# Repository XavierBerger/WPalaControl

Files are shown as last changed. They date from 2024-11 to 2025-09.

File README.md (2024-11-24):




# WPalaControl

**WPalaControl** is a device designed to control and monitor Fumis-based stoves using a D1 Mini.  
It allows you to power on/off, adjust the set point, change fan speeds, and retrieve status, alarms, and temperature data from your stove.  

It supports native HTTP requests which makes it fully compatible with all existing Palazzetti/Fumis home automation plugins/apps.  

It also integrates with MQTT to monitor/control your stove in a much more efficient way.  

## Stove Compatibility

WPalaControl is compatible with stoves using the Fumis Controller, which is used by many manufacturers, including:  
  
Palazzetti / Jotul / TurboFonte / Godin / Fonte Flamme / Invicta / Casatelli / Alpis / Faizen / HETA / ...

To determine if your stove is compatible with WPalaControl, look for the following Control Panel or Motherboard:  
Fumis ControllerFumis Controller

## Home Automation compatibility

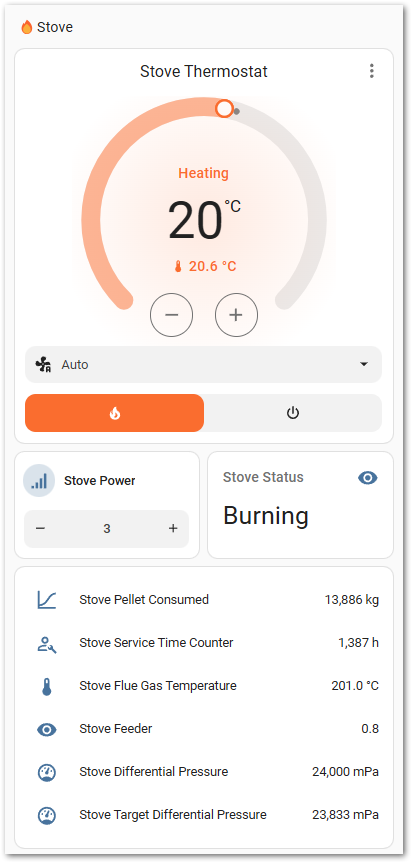
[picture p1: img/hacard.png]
hacard
| Logo HASS | [MQTT Integration](https://www.home-assistant.io/integrations/mqtt/) (autodiscovery) <br> Most options and fans control |  |
| --- | --- | --- |
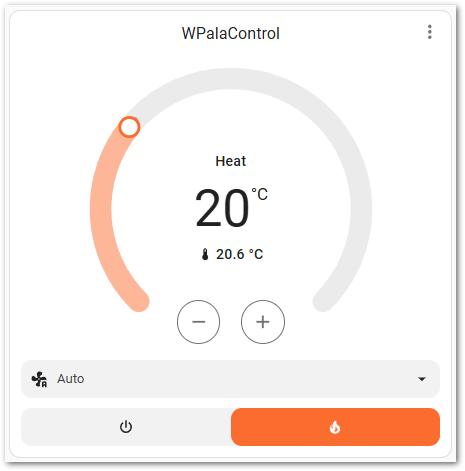
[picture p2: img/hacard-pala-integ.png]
hacard-pala-integ
| Logo HASS | [Palazzetti Integration](https://www.home-assistant.io/integrations/palazzetti)<br> (2024.11 minimum) <br> Basic implementation for now |  |
| Logo Jeedom | [Palazzetti plugin](https://www.jeedom.com/market/index.php?v=d&p=market_display&id=3104) | Jeedom widget |

## Make/Get your adapter

complete Module

🔧 If you want to build it yourself, you can find all details here : [BUILD](BUILD.md) 🔧  

🛍️🚀 Otherwise, I'm producing some small batches and offering it ready-to-use here :  
Tindie product (https://www.tindie.com/products/35770/)  

## Connect

⚠️ **Before connecting, please check that you are using the correct cable**  
For Hardware V1.x: please use a **Crossed** cable  
For Hardware V2.x: please use a **Straight** cable  
_(Hardware version is written on the box and on the PCB)_

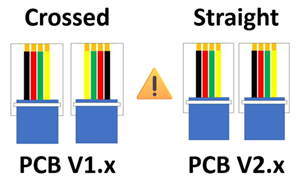
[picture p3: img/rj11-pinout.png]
WPalaControl rj11


✅If your stove has an accessible RJ12 connector, simply connect the cable.  

🔍If not, you'll need an additional cable and a splitter.  
➡️ More details can be found in the [Splitter Cabling documentation](SPLITTERCABLING.md)

## First Boot

During the first Boot, the WPalaControl creates its own Wi-Fi network (AP mode)  

Firmware version **3.2.0 and higher**:  

- Network SSID : `WPalaControl`
- Password : `password`

Version **3.1.x and lower**:  

- Network SSID : `WirelessPalaControlXXXX`
- Password : `PasswordPalaControl`

You should be automatically redirected to the module page.  
If not, go to 👉 <http://wpalacontrol.local> 👈

## Configuration pages

### Status

Provides useful informations about the module and the stove.  
**The stove SN appears then followed, 1 minute later, by refreshed stove information**  
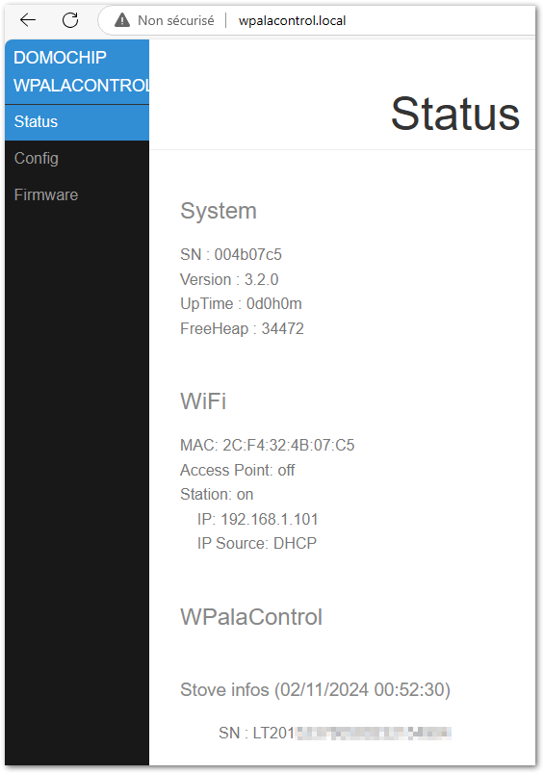
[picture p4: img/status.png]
status screenshot
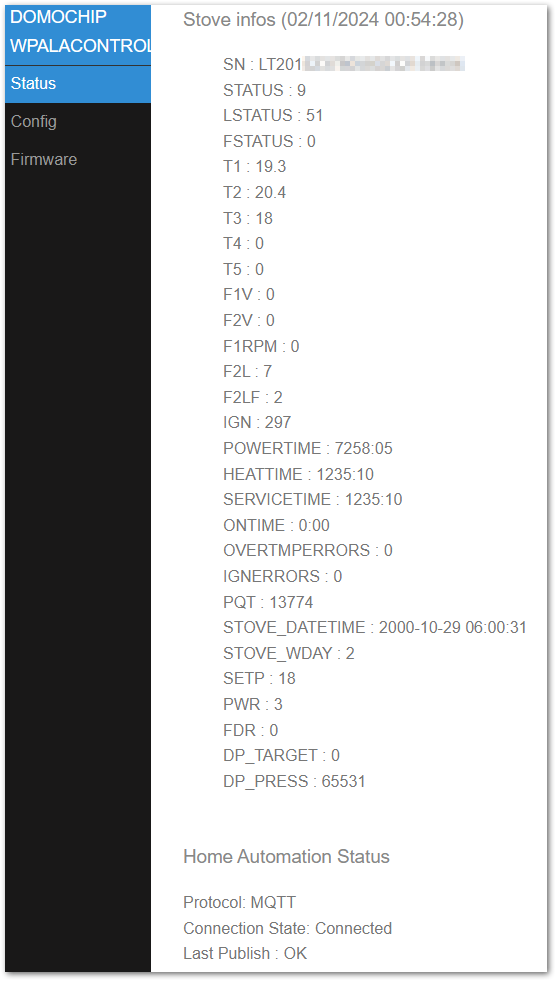
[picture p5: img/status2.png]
status2 screenshot


### Config

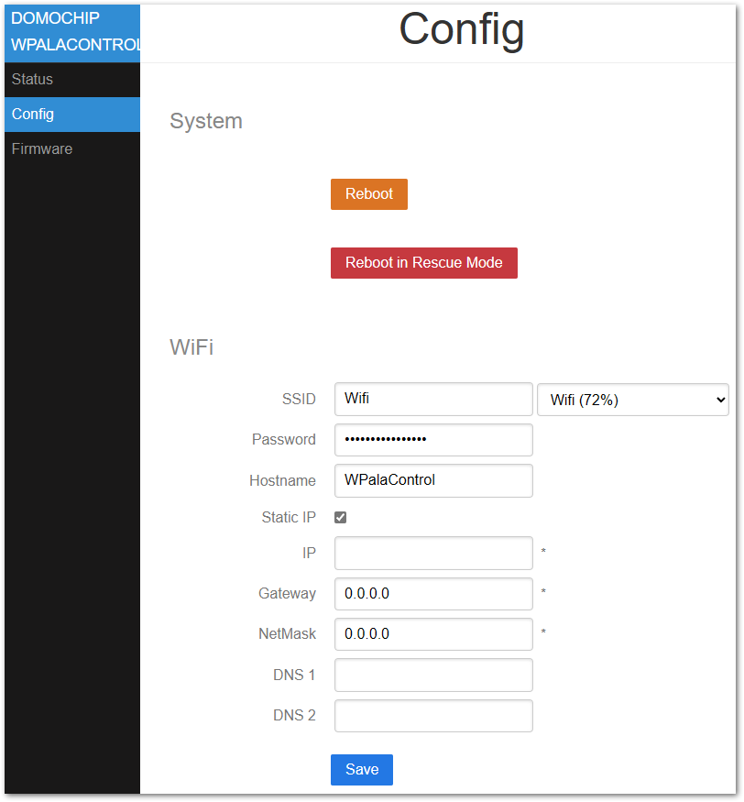
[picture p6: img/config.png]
config screenshot


#### System

- **Reboot**: restart the module
- **Reboot in Rescue Mode**: restart the module with default configuration

#### WiFi

- **ssid & password**: IDs of your Wifi Network  
- **hostname**: name of ESP on the network  
- **IP, GW, NetMask, DNS1&2**: Fixed IP configuration  

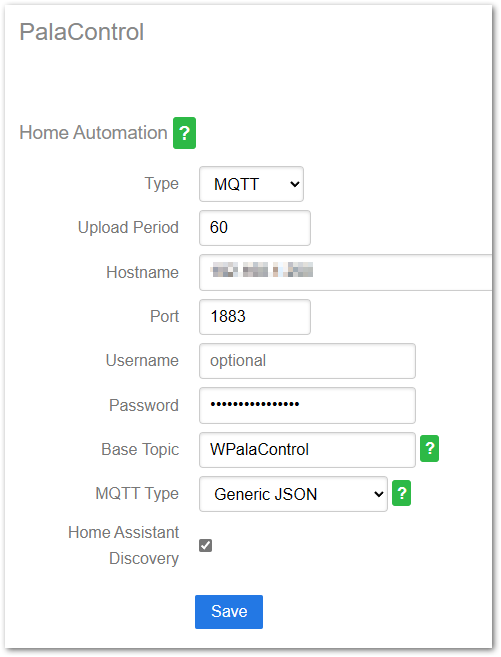
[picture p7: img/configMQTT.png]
configMQTT screenshot


#### PalaControl - Home Automation

- **Type**: enable/disable MQTT communication  
- **Upload Period**: set the refresh interval of stove information (in seconds)  
- **Hostname, Port, Username, Password**: MQTT server details (username and password are - optional)  
- **Base Topic**: prefix for WPalaControl topic structure  
- **MQTT Type**: defines MQTT topics and data structure:  
  - **Generic**: publish raw values under the base topic (e.g. "{baseTopic}/T1" = "*20.00*")
  - **Generic JSON**: publish values JSON to "category" topic under base topic (e.g. "{baseTopic}/TMPS" = "*{"INFO":{"CMD":"GET TMPS","RSP":"OK......*")
  - **Generic Categorized**: publish raw values to "category" topic under base topic (e.g. "{baseTopic}/TMPS/T1" = "*20.00*")
- **Home Assistant Discovery**: Enable/disable Home Assistant auto-discovery

### Firmware

Aallows you to flash a new firmware version directly from GitHub releases or using `WPalaControl.*.bin` or `WirelessPalaControl.*.bin` file:  
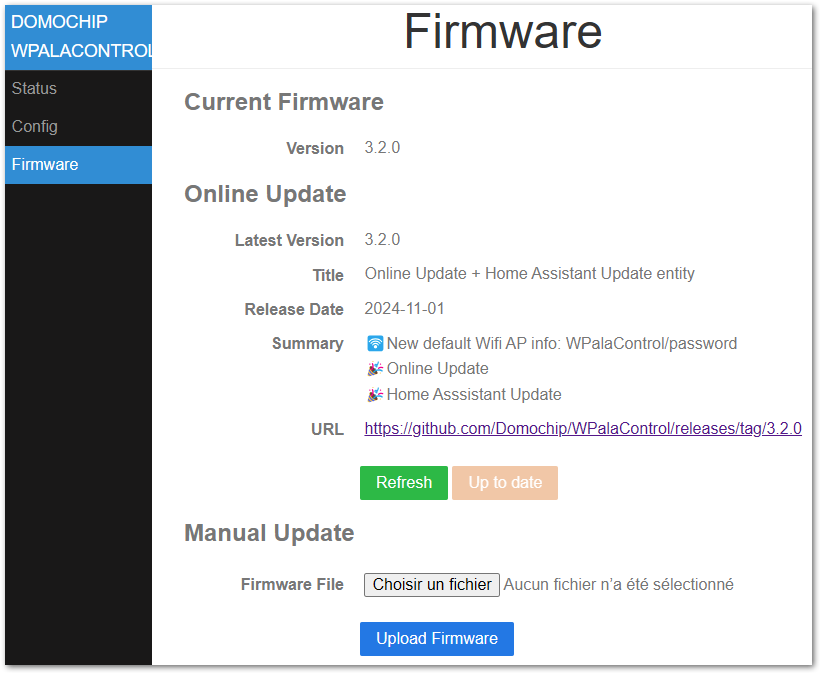
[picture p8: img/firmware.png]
firmware screenshot
  
Ensure the module has Internet access and/or DNS configured if IP address is static

## Use it

### HTTP

Natively, HTTP GET request can be sent directly to the module.  

```
http://wpalacontrol.local/cgi-bin/sendmsg.lua?cmd={command}
```

### MQTT

Send commands via MQTT to `%BaseTopic%/cmd` topic once MQTT is configured.  
Execution result is:

- published following the configured MQTT Type
- published on `%BaseTopic%/result` in JSON format

Module connection status is published to `%BaseTopic%/connected`:

- 0: not connected
- 1: connected but no communication with the stove
- 2: module and stove connected

### Command List
  
- `GET+STDT`: get static data
- `GET+ALLS`: get all status data
- `GET+STAT`: get status of the stove⏲️
- `GET+TMPS`: get temperatures of the stove⏲️
- `GET+FAND`: get Fan values⏲️
- `GET+SETP`: get current Set Point (desired temperature)⏲️
- `GET+POWR`: get current power (1-5)⏲️
- `GET+CUNT`: get some counters
- `GET+CNTR`: get some counters (same as GET+CUNT)⏲️
- `GET+DPRS`: get delta pressure data⏲️
- `GET+TIME`: get stove clock data⏲️
- `GET+IOPT`: get IO ports status
- `GET+SERN`: get stove Serial Number
- `GET+MDVE`: get stove model and fw version
- `GET+CHRD`: get chrono data
- `GET+PARM+92`: get parameter (ex : 92=pellet type (1-3))
- `GET+HPAR+57`: get hidden parameter (ex : 57=% of pellet to feed for pellet type 3)
- `BKP+PARM+CSV`: get all parameters in a CSV file (HTTP only) ✨
- `BKP+PARM+JSON`: get all parameters in a JSON file (HTTP only) ✨
- `BKP+HPAR+CSV`: get all hidden parameters in a CSV file (HTTP only) ✨
- `BKP+HPAR+JSON`: get all hidden parameters in a JSON file (HTTP only) ✨
- `CMD+ON`: turn stove ON
- `CMD+OFF`: turn stove OFF
- `SET+POWR+3`: set power (1-5)
- `SET+PWRU`: increase power by 1 unit
- `SET+PWRD`: decrease power by 1 unit
- `SET+SETP+20`: set Set Point (desired temperature)
- `SET+STPF+19.8`: set Set Point with a 0.2° precision (depend of your stove model)✨
- `SET+STPU`: increase Set Point by 1 unit
- `SET+STPD`: decrease Set Point by 1 unit
- `SET+RFAN+7`: set Room Fan value (0-5;6=Max;7=Auto)
- `SET+FN2U`: increase Room Fan by 1 unit
- `SET+FN2D`: decrease Room Fan by 1 unit
- `SET+FN3L+0`: set Room Fan 3 value (0-5)
- `SET+FN4L+0`: set Room Fan 4 value (0-5)
- `SET+SLNT+0`: set Silent mode value (0-1)
- `SET+TIME+2023-12-28+19:42:00`: set stove Date and Time (2000-2099) (1-12) (1-31) (0-23) (0-59) (0-59)
- `SET+CSST+0`: set Chrono Status value (0-1)
- `SET+CSTH+2+18`: set Chrono Program Start Hour (1-6) (0-23)
- `SET+CSTM+2+30`: set Chrono Program Start Minute (1-6) (0-59)
- `SET+CSPH+2+22`: set Chrono Program Stop Hour (1-6) (0-23)
- `SET+CSPM+2+45`: set Chrono Program Stop Minute (1-6) (0-59)
- `SET+CSET+2+19`: set Chrono Program Set Point (1-6) (desired temperature)
- `SET+CDAY+7+3+6`: set Chrono Program for week day (Day-Mem-Prog) (1-7) (1-3) (1-6)
- `SET+CPRD+1+19+18+30+22+45`: set Chrono Program data (Prog-Temp-StartH-StartM-StopH-StopM) (1-6) (temperature) (0-23) (0-59) (0-23) (0-59)
- `SET+PARM+92+2`: set parameter 92 to value 2 (ex : 92=pellet type (1-3))
- `SET+HPAR+57+95`: set hidden parameter 57 to value 95 (ex : 57=% of pellet to feed for pellet type 3)

⏲️: Published automatically  
✨: WPalaControl specific commands

### Description

MQTT infos published every "Upload Period":

- `STATUS`: status of the stove
- `LSTATUS`: status of the stove
- `T1`, `T2`, `T3`, `T4`, `T5`: temperature of the stove
- `F1V`, `F2V`, `F2L`, `F2LF`, `F3L`, `F4L`: fan values (meaning depend of your stove model)
- `IGN`: ignition counter
- `IGNERRORS`: ignition error counter
- `POWERTIME`: total heating time (hour:minute)
- `HEATTIME`: ??? (hour:minute)
- `SERVICETIME`: heating time since last maintenance (hour:minute)
- `ONTIME`: time from last power ON (hour:minute)
- `OVERTMPERRORS`: overtemperature error counter
- `STOVE_DATETIME`: date of the stove
- `STOVE_WDAY`: week day of the stove
- `SETP`: current Set Point (desired temperature)
- `PQT`: wood pellet consumption
- `PWR`: current power (1-5)
- `FDR`: feeder
- `DP_TARGET`: delta pressure target
- `DP_PRESS`: actual delta pressure

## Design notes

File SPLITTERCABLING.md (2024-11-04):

## Splitter Cabling

If your stove has no visible RJ12 connector, you'll neded to add a cable and a splitter between the controller and the control panel like this:  

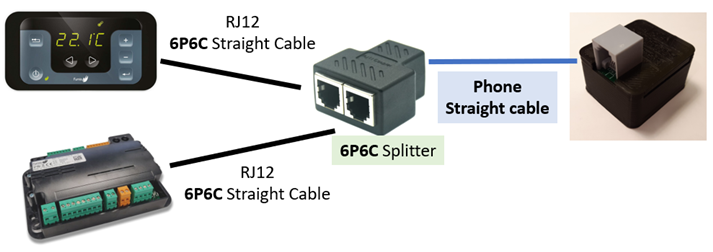
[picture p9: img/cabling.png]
WPalaControl cabling


The splitter should correspond to this small schematic :  
WPalaControl schematic-splitter

I'm offering these as an option on my store if needed

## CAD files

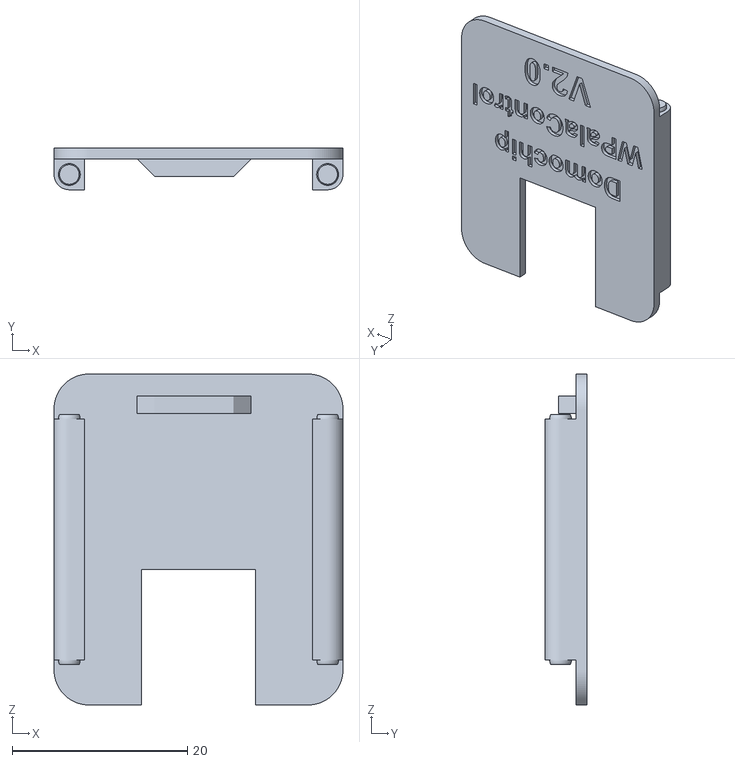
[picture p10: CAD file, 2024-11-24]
box/WPalaControl Lid.stl
33.0 x 4.75 x 37.8

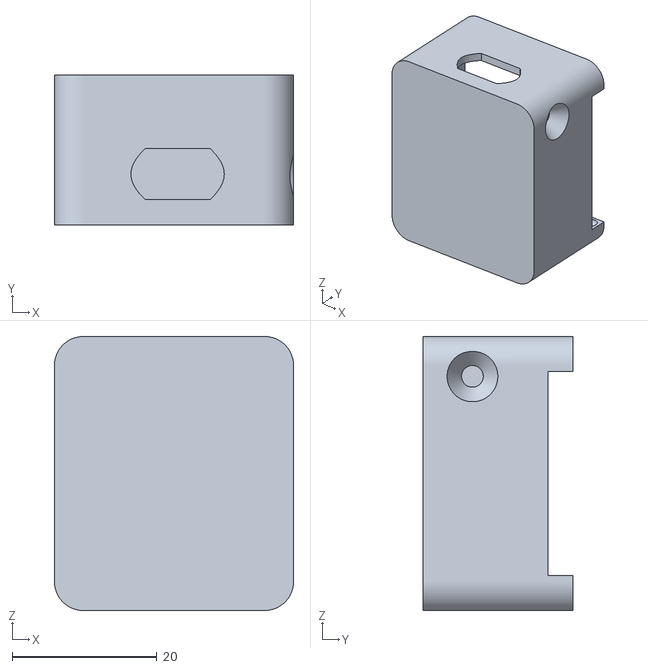
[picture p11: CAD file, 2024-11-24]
box/WPalaControl Box.stl
33.0 x 20.8 x 37.8

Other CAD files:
box/WPalaControl v17.f3d

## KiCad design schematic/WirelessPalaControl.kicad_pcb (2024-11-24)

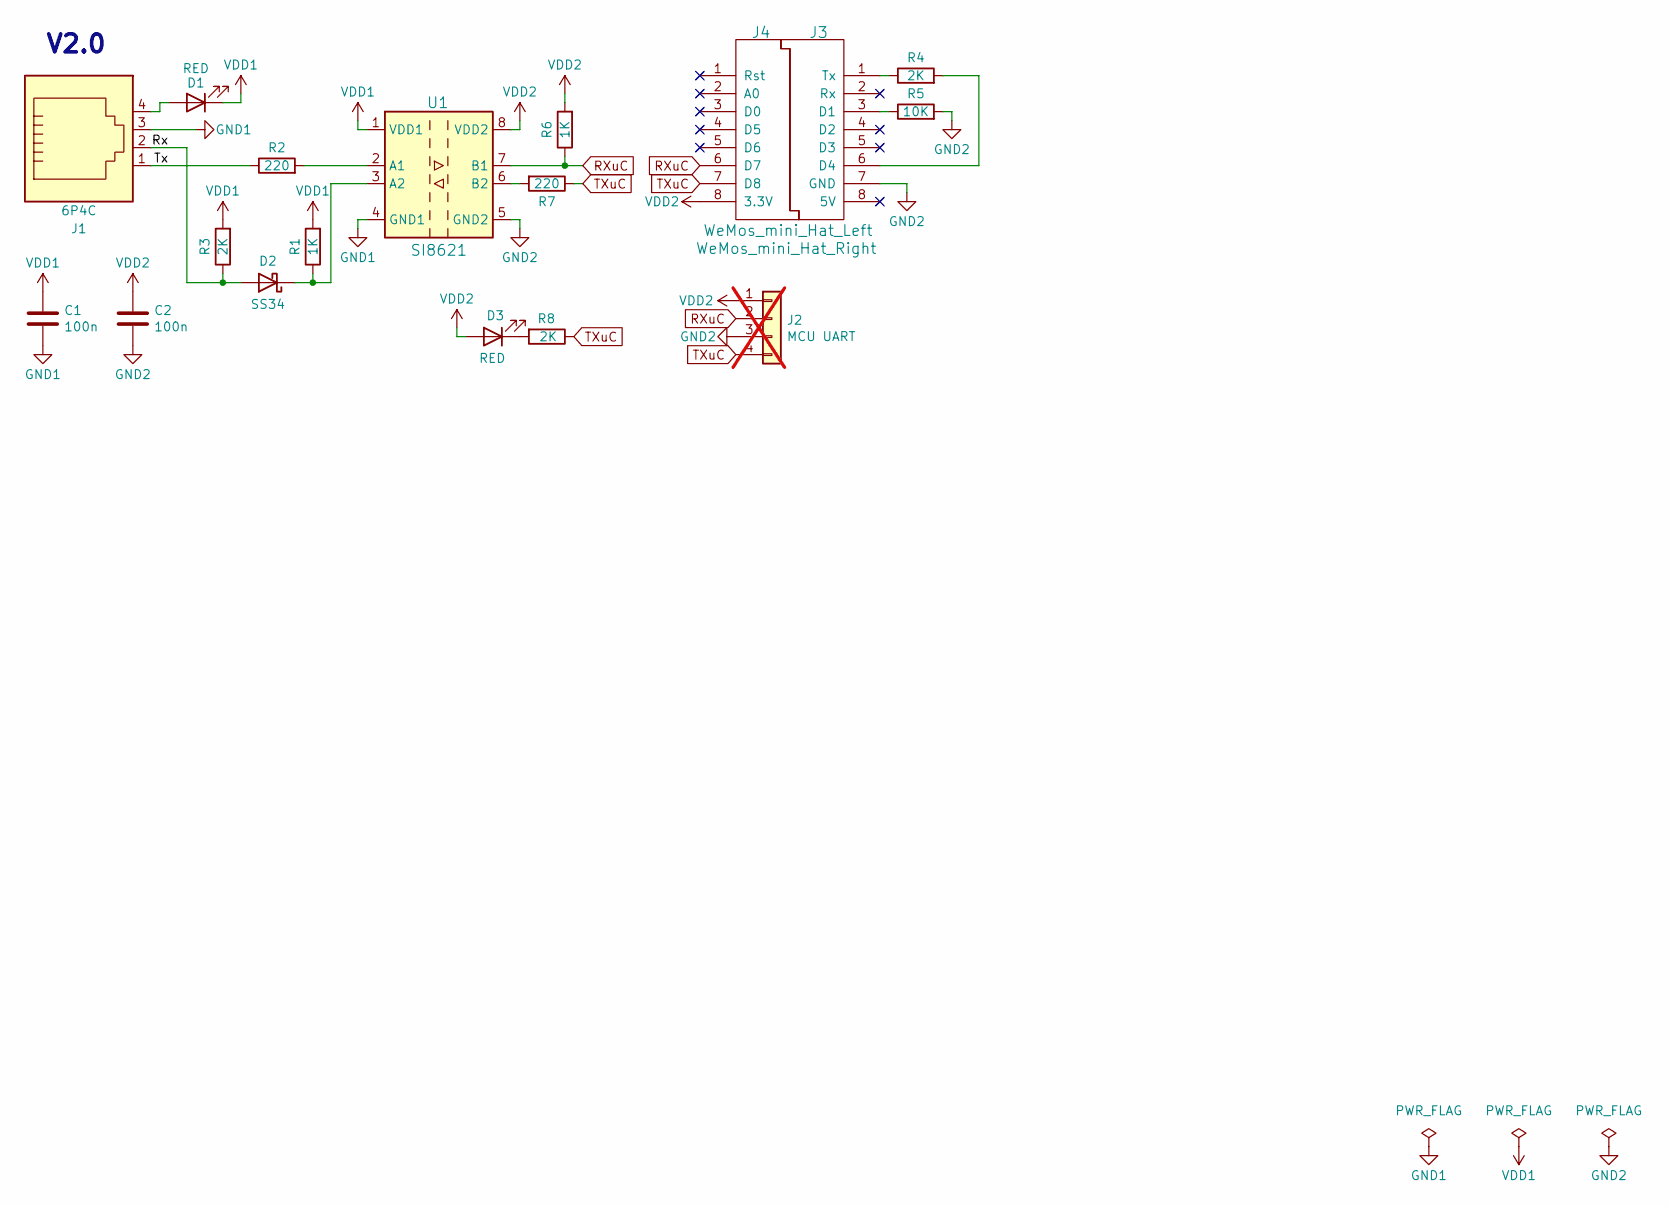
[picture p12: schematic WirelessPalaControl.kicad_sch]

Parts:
C1, C2: 100n; C_0805_2012Metric_Pad1.18x1.45mm_HandSolder; LCSC C49678
D1, D3: RED; LED_0805_2012Metric_Pad1.15x1.40mm_HandSolder; LCSC C84256
D2: SS34; D_SMA; LCSC C8678
J1: 6P4C; Ali_RJ11; LCSC C189749
J2: MCU UART; PinHeader_1x04_P2.54mm_Vertical; not fitted
J3: WeMos_mini_Hat_Left; WeMos_D1_mini_Hat_Left; LCSC C7509515
J4: WeMos_mini_Hat_Right; WeMos_D1_mini_Hat_Right; LCSC C7509515
R1, R6: 1K; R_0805_2012Metric_Pad1.20x1.40mm_HandSolder; LCSC C17513
R2, R7: 220; R_0805_2012Metric_Pad1.20x1.40mm_HandSolder; LCSC C17557
R3, R4, R8: 2K; R_0805_2012Metric_Pad1.20x1.40mm_HandSolder; LCSC C17604
R5: 10K; R_0805_2012Metric_Pad1.20x1.40mm_HandSolder; LCSC C17414
U1: SI8621; SOIC-8_3.9x4.9mm_P1.27mm; LCSC C461877

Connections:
/Rx: D2.2 (A), J1.2, R3.1
/Tx: J1.1, R2.1
GND1: C1.2, J1.3, U1.4 (GND1)
GND2: C2.2, J2.3, J3.7 (GND), R5.2, U1.5 (GND2)
unnamed: D1.2 (A), J1.4
unnamed: D2.1 (K), R1.1, U1.3 (A2)
unnamed: D3.1 (K), R8.2
unnamed: J3.3 (D1), R5.1
unnamed: J3.6 (D4), R4.2
unnamed: J3.1 (Tx), R4.1
unnamed: R2.2, U1.2 (A1)
unnamed: R7.2, U1.6 (B2)
RXuC: J2.2, J4.6 (D7), R6.1, U1.7 (B1)
TXuC: J2.4, J4.7 (D8), R7.1, R8.1
VDD1: C1.1, D1.1 (K), R1.2, R3.2, U1.1 (VDD1)
VDD2: C2.1, D3.2 (A), J2.1, J4.8 (3.3V), R6.2, U1.8 (VDD2)

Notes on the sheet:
V2.0

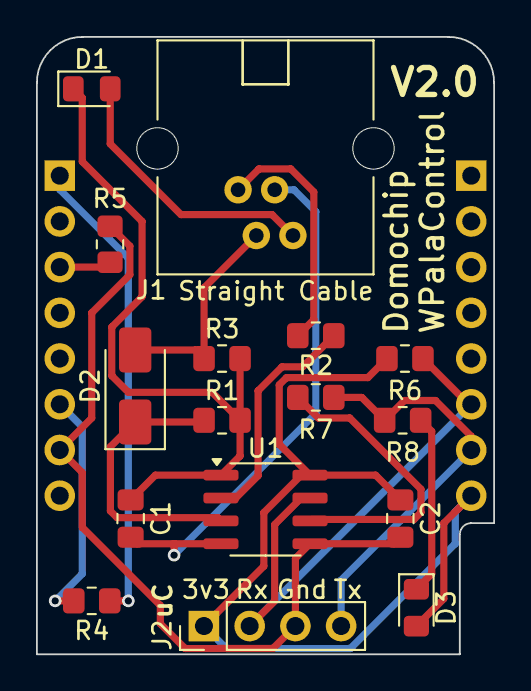
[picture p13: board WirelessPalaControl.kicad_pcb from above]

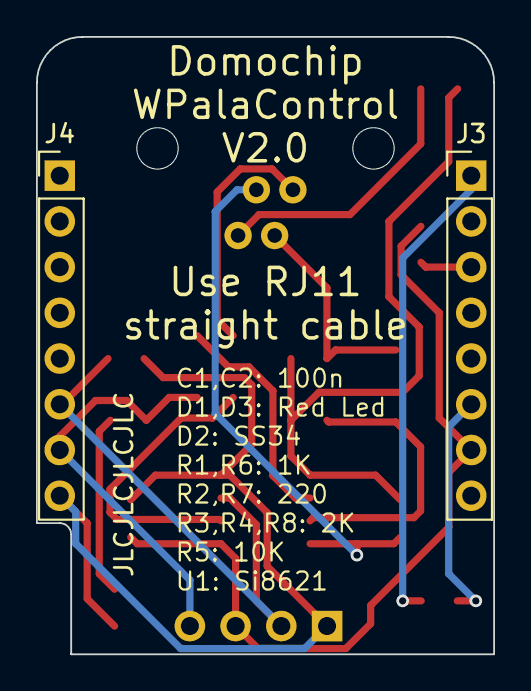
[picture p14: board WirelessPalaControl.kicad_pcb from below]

Board: 2 copper layers, 25.4 x 34.3 mm, 18 parts (2 on the bottom side), 16 nets.

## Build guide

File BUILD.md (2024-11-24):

## Build your adapter

This adapter is designed to works with a D1 Mini (ESP8266) but it provides convenient header pins to use it with any other uController.

It is designed by Palazzetti using a Si8621 (Silicon Labs Isolator) to provide electrical isolation between uController and Stove electronic.  
This design uses exact same schematic and components.

### Schematic

All files are inside `schematic` subfolder and has been designed with KiCad (free and open source)  

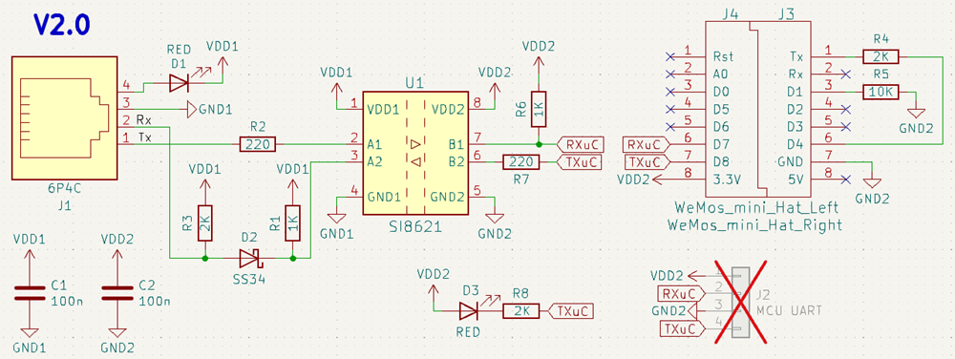
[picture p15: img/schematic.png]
WPalaControl schematic


### PCB

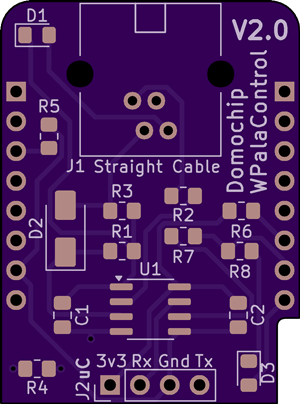
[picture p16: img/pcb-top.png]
WPalaControl PCB Top
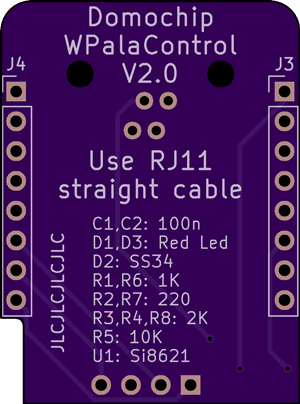
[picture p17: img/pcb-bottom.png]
WPalaControl PCB Bottom
  

WPalaControl 3boards  

*I'm producing small batches of this adapter.*  
*If you are interested, you can find it here: [WPalaControl on tindie](https://www.tindie.com/products/35770/)* 🛍️

### Box

Box project (Fusion 360 & STL) can be found into `box` folder

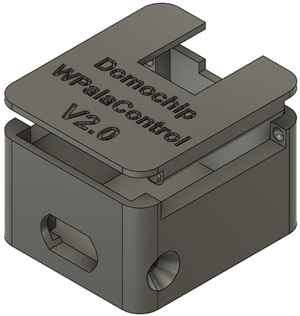
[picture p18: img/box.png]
WPalaControl box


### Firmware

Source code can be compiled using VSCode/PlatformIO and flashed onto a D1 Mini  
Or  
Download latest release in [Release section](https://github.com/Domochip/WPalaControl/releases)

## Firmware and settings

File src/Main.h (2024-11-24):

#ifndef Main_h
#define Main_h

#include <Arduino.h>

// Helper macros to convert a define to a string
#define STRINGIFY(x) #x
#define TOSTRING(x) STRINGIFY(x)

// ----- Should be modified for your application -----
#define CUSTOM_APP_MANUFACTURER "Domochip"
#define CUSTOM_APP_MODEL "WPalaControl"
#define CUSTOM_APP_CLASS WPalaControl
#define VERSION_NUMBER "3.5.0"

#define CUSTOM_APP_HEADER TOSTRING(CUSTOM_APP_CLASS.h) // calculated header file "{CUSTOM_APP_CLASS}.h"
#define DEFAULT_AP_SSID CUSTOM_APP_MODEL               // Default Access Point SSID "{CUSTOM_APP_MODEL}"
#define DEFAULT_AP_PSK "password"                      // Default Access Point Password

// Control EventSourceMan code (To be used by Application if EventSource server is needed)
#define EVTSRC_ENABLED 1
#define EVTSRC_MAX_CLIENTS 2
#define EVTSRC_KEEPALIVE_ENABLED 0

// Enable developper mode
#define DEVELOPPER_MODE 0

// Log Serial Object
#ifdef ESP8266
#define LOG_SERIAL Serial1
#else
#define LOG_SERIAL Serial
#endif
// Choose Log Serial Speed
#define LOG_SERIAL_SPEED 38400

// Log Serial Macros
#ifdef LOG_SERIAL
#define LOG_SERIAL_PRINT(...) LOG_SERIAL.print(__VA_ARGS__)
#define LOG_SERIAL_PRINTLN(...) LOG_SERIAL.println(__VA_ARGS__)
#define LOG_SERIAL_PRINTF(...) LOG_SERIAL.printf(__VA_ARGS__)
#define LOG_SERIAL_PRINTF_P(...) LOG_SERIAL.printf_P(__VA_ARGS__)
#else
#define LOG_SERIAL_PRINT(...)
#define LOG_SERIAL_PRINTLN(...)
#define LOG_SERIAL_PRINTF(...)
#define LOG_SERIAL_PRINTF_P(...)
#endif

// Choose Pin used to boot in Rescue Mode
// #define RESCUE_BTN_PIN 2

// Define time to wait for Rescue press (in s)
// #define RESCUE_BUTTON_WAIT 3

// Status LED
// #define STATUS_LED_SETUP pinMode(XX, OUTPUT);pinMode(XX, OUTPUT);
// #define STATUS_LED_OFF digitalWrite(XX, HIGH);digitalWrite(XX, HIGH);
// #define STATUS_LED_ERROR digitalWrite(XX, HIGH);digitalWrite(XX, HIGH);
// #define STATUS_LED_WARNING digitalWrite(XX, HIGH);digitalWrite(XX, HIGH);
// #define STATUS_LED_GOOD digitalWrite(XX, HIGH);digitalWrite(XX, HIGH);

// construct Version text
#if DEVELOPPER_MODE
#define VERSION VERSION_NUMBER "-DEV"
#else
#define VERSION VERSION_NUMBER
#endif

#endif

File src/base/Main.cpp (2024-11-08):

#ifdef ESP8266
#include <ESP8266WiFi.h>
#include <ESP8266WebServer.h>
using WebServer = ESP8266WebServer;
#else
#include <WiFi.h>
#include <WebServer.h>
#endif
#include <EEPROM.h>
#include <LittleFS.h>
#include <FS.h>

#include "Version.h"
#include "../Main.h"
#include "SystemState.h"
#include "Application.h"
#include "Core.h"
#include "WifiMan.h"

// include Custom Application header file
#include CUSTOM_APP_HEADER

// WebServer
WebServer server(80);

// Core App
Core core;

// WifiMan App
WifiMan wifiMan;

// Custom App
CUSTOM_APP_CLASS custom;

//-----------------------------------------------------------------------
// Setup function
//-----------------------------------------------------------------------
void setup()
{
#ifdef LOG_SERIAL
  LOG_SERIAL.begin(LOG_SERIAL_SPEED);
  LOG_SERIAL_PRINTLN();
  LOG_SERIAL_PRINTLN();
  LOG_SERIAL.flush();
#endif

#ifdef STATUS_LED_SETUP
  STATUS_LED_SETUP
#endif
#ifdef STATUS_LED_ERROR
  STATUS_LED_ERROR
#endif

  LOG_SERIAL_PRINTLN(F(CUSTOM_APP_MANUFACTURER " " CUSTOM_APP_MODEL " " VERSION));
  LOG_SERIAL_PRINTLN(F("---Booting---"));

#ifndef RESCUE_BUTTON_WAIT
#define RESCUE_BUTTON_WAIT 3
#endif

  bool skipExistingConfig = false;

  // look into EEPROM for Rescue mode flag
  EEPROM.begin(4);
  skipExistingConfig = EEPROM.read(0) != 0;
  if (skipExistingConfig)
    EEPROM.write(0, 0);
  EEPROM.end();

#ifdef RESCUE_BTN_PIN
  // if config already skipped, don't wait for rescue button
  if (!skipExistingConfig)
  {
    LOG_SERIAL_PRINTF_P(PSTR("Wait Rescue button for %d seconds\n"), RESCUE_BUTTON_WAIT);

    pinMode(RESCUE_BTN_PIN, (RESCUE_BTN_PIN != 16) ? INPUT_PULLUP : INPUT);
    for (int i = 0; i < 100 && skipExistingConfig == false; i++)
    {
      if (digitalRead(RESCUE_BTN_PIN) == LOW)
        skipExistingConfig = true;
      delay(RESCUE_BUTTON_WAIT * 10);
    }
  }
#endif

  if (skipExistingConfig)
  {
    LOG_SERIAL_PRINTLN(F("-> RESCUE MODE : Stored configuration won't be loaded."));
  }
#ifdef ESP8266
  if (!LittleFS.begin())
#else
  if (!LittleFS.begin(true))
#endif
  {
    LOG_SERIAL_PRINTLN(F("/!\\   File System Mount Failed   /!\\"));
    LOG_SERIAL_PRINTLN(F("/!\\ Configuration can't be saved /!\\"));
  }

  // Init Core
  core.init(skipExistingConfig);

  // Init WiFi
  wifiMan.init(skipExistingConfig);

  // Init Custom Application
  custom.init(skipExistingConfig);

  LOG_SERIAL_PRINT(F("Start WebServer : "));

  core.initWebServer(server);
  wifiMan.initWebServer(server);
  custom.initWebServer(server);

  server.begin();

  LOG_SERIAL_PRINTLN(F("OK"));
  LOG_SERIAL_PRINTLN(F("---End of setup()---"));
}

//-----------------------------------------------------------------------
// Main Loop function
//-----------------------------------------------------------------------
void loop(void)
{

  // Handle WebServer
  server.handleClient();

  if (!SystemState::pauseCustomApp && !SystemState::shouldReboot)
    custom.run();

  wifiMan.run();

  if (SystemState::shouldReboot)
  {
#ifdef LOG_SERIAL
    LOG_SERIAL_PRINTLN(F("Rebooting..."));
    delay(100);
    LOG_SERIAL.end();
#endif
    ESP.restart();
  }
}

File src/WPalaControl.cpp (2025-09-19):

#include "WPalaControl.h"

#ifdef ESP8266
#define PALA_SERIAL Serial
#else
#define PALA_SERIAL Serial2
#endif

// Serial management functions -------------
int WPalaControl::myOpenSerial(uint32_t baudrate)
{
#ifdef ESP8266
  LOG_SERIAL.flush();
  PALA_SERIAL.begin(baudrate);
  PALA_SERIAL.pins(15, 13); // swap ESP8266 pins to alternative positions (D7(GPIO13)(RX)/D8(GPIO15)(TX))
  pinMode(1, INPUT);
#else
  PALA_SERIAL.begin(baudrate, SERIAL_8N1, 23, 5); // set ESP32 pins to match hat position (IO23(RX)/IO5(TX))
#endif
  return 0;
}
void WPalaControl::myCloseSerial()
{
  PALA_SERIAL.end();
  // set TX PIN to OUTPUT HIGH to avoid stove bus blocking
#ifdef ESP8266
  pinMode(15, OUTPUT);
  digitalWrite(15, HIGH);
#else
  pinMode(5, OUTPUT);
  digitalWrite(5, HIGH);
#endif
}
int WPalaControl::mySelectSerial(unsigned long timeout)
{
  size_t avail;
  unsigned long startmillis = millis();
  while ((avail = PALA_SERIAL.available()) == 0 && (startmillis + timeout) > millis())
    ;

  return avail;
}
size_t WPalaControl::myReadSerial(void *buf, size_t count) { return PALA_SERIAL.read((char *)buf, count); }
size_t WPalaControl::myWriteSerial(const void *buf, size_t count) { return PALA_SERIAL.write((const uint8_t *)buf, count); }
int WPalaControl::myDrainSerial()
{
  PALA_SERIAL.flush(); // On ESP, Serial.flush() is drain
  return 0;
}
int WPalaControl::myFlushSerial()
{
  PALA_SERIAL.flush();
  while (PALA_SERIAL.read() != -1)
    ; // flush RX buffer
  return 0;
}
void WPalaControl::myUSleep(unsigned long usecond) { delayMicroseconds(usecond); }

void WPalaControl::mqttConnectedCallback(MQTTMan *mqttMan, bool firstConnection)
{
  // Subscribe command topic --------------------------------
  String cmdTopic = _ha.mqtt.generic.baseTopic;
  MQTTMan::prepareTopic(cmdTopic);

  switch (_ha.mqtt.type) // switch on MQTT type
  {
  case HA_MQTT_GENERIC:
  case HA_MQTT_GENERIC_JSON:
  case HA_MQTT_GENERIC_CATEGORIZED:
    cmdTopic += F("cmd");
    break;
  }

  if (firstConnection)
    mqttMan->publish(cmdTopic.c_str(), ""); // make empty publish only for firstConnection
  mqttMan->subscribe(cmdTopic.c_str());

  // Subscribe to update/install topic -----------------------
  String updateInstalltopic(_ha.mqtt.generic.baseTopic);
  MQTTMan::prepareTopic(updateInstalltopic);
  updateInstalltopic += F("update/install");
  mqttMan->subscribe(updateInstalltopic.c_str());

  // raise flag to publish Home Assistant discovery data
  _needPublishHassDiscovery = true;
}

void WPalaControl::mqttDisconnectedCallback()
{
  // if MQTT is disconnected, MQTT Reconnection will publish "1" to connectedTopic
  _publishedStoveConnected = false;
}

void WPalaControl::mqttCallback(char *topic, uint8_t *payload, unsigned int length)
{
  // calculate command topic
  String cmdTopic = _ha.mqtt.generic.baseTopic;
  MQTTMan::prepareTopic(cmdTopic);

  switch (_ha.mqtt.type) // switch on MQTT type
  {
  case HA_MQTT_GENERIC:
  case HA_MQTT_GENERIC_JSON:
  case HA_MQTT_GENERIC_CATEGORIZED:
    cmdTopic += F("cmd");
    break;
  }
  // if topic is command one
  if (cmdTopic == topic)
  {
    String cmd;
    String strJson;

    // convert payload to String cmd
    cmd.concat((char *)payload, length);

    // replace '+' by ' '
    cmd.replace('+', ' ');

    // execute Palazzetti command
    executePalaCmd(cmd, strJson, true);

    // publish json result to MQTT
    String baseTopic = _ha.mqtt.generic.baseTopic;
    MQTTMan::prepareTopic(baseTopic);
    String resTopic(baseTopic);
    resTopic += F("result");
    _mqttMan.publish(resTopic.c_str(), strJson.c_str());
  }

  // if topic ends with "/update/install"
  if (String(topic).endsWith(F("/update/install")))
  {
    String version;
    String retMsg;
    unsigned long lastProgressPublish = 0;

    // result topic is topic without the last 8 characters ("/install")
    String resTopic(topic);
    resTopic.remove(resTopic.length() - 8);

    if (length > 10)
      retMsg = F("Version is too long");
    else
    {
      // convert payload to String
      version.concat((char *)payload, length);

      // Define the progress callback function
      std::function<void(size_t, size_t)> progressCallback = [this, &resTopic, &lastProgressPublish](size_t progress, size_t total)
      {
        // if last progress publish is less than 500ms ago then return
        if (millis() - lastProgressPublish < 500)
          return;
        lastProgressPublish = millis();

        uint8_t percent = (progress * 100) / total;
        LOG_SERIAL_PRINTF_P(PSTR("Progress: %d%%\n"), percent);
        String payload = String(F("{\"update_percentage\":")) + percent + '}';
        _mqttMan.publish(resTopic.c_str(), payload.c_str(), true);
      };

      SystemState::shouldReboot = updateFirmware(version.c_str(), retMsg, progressCallback);
    }

    if (SystemState::shouldReboot)
      retMsg = F("{\"update_percentage\":null,\"in_progress\":true}");
    else
    {
      _mqttMan.publish(topic, (String(F("Update failed: ")) + retMsg).c_str(), true);
      retMsg = F("{\"in_progress\":false}");
    }

    // publish result
    _mqttMan.publish(resTopic.c_str(), retMsg.c_str(), true);
  }
}

void WPalaControl::mqttPublishStoveConnected(bool stoveConnected)
{
  if (_mqttMan.connected() && _publishedStoveConnected != stoveConnected)
  {
    // if Stove is connected, publish 2 to connected topic otherwise fallback to 1
    _mqttMan.publishToConnectedTopic((stoveConnected ? "2" : "1"));
    _needPublishHassDiscovery = true; // raise flag to publish Home Assistant discovery data
    _publishedStoveConnected = stoveConnected;
  }
}
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

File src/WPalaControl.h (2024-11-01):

#ifndef WPalaControl_h
#define WPalaControl_h

#include "Main.h"
#include "base/MQTTMan.h"
#include "base/EventSourceMan.h"
#include "base/Application.h"

const char appDataPredefPassword[] PROGMEM = "ewcXoCt4HHjZUvY1";

#include "data/status2.html.gz.h"
#include "data/config2.html.gz.h"

#include <Palazzetti.h>
#include <WiFiUdp.h>

class WPalaControl : public Application
{
private:
#define HA_MQTT_GENERIC 0
#define HA_MQTT_GENERIC_JSON 1
#define HA_MQTT_GENERIC_CATEGORIZED 2

  typedef struct
  {
    byte type = HA_MQTT_GENERIC_JSON;
    uint32_t port = 1883;
    char username[32 + 1] = {0};
    char password[64 + 1] = {0};
    struct
    {
      char baseTopic[64 + 1] = {0};
    } generic;
    bool hassDiscoveryEnabled = true;
    char hassDiscoveryPrefix[32 + 1] = {0};
  } MQTT;

#define HA_PROTO_DISABLED 0
#define HA_PROTO_MQTT 1

  typedef struct
  {
    byte protocol = HA_PROTO_DISABLED;
    char hostname[64 + 1] = {0};
    uint16_t uploadPeriod = 60;
    MQTT mqtt;
  } HomeAutomation;

  HomeAutomation _ha;
  int _haSendResult = 0;
  WiFiClient _wifiClient;
  MQTTMan _mqttMan;
  EventSourceMan _eventSourceMan;
  WiFiUDP _udpServer;

  Palazzetti _Pala;
  unsigned long _lastAllStatusRefreshMillis = 0;

  bool _needPublish = false;
  Ticker _publishTicker;
  bool _publishedStoveConnected = false;
  bool _needPublishHassDiscovery = false;
  bool _needPublishUpdate = false;
  Ticker _publishUpdateTicker;

  int myOpenSerial(uint32_t baudrate);
  void myCloseSerial();
  int mySelectSerial(unsigned long timeout);
  size_t myReadSerial(void *buf, size_t count);
  size_t myWriteSerial(const void *buf, size_t count);
  int myDrainSerial();
  int myFlushSerial();
  void myUSleep(unsigned long usecond);

  void mqttConnectedCallback(MQTTMan *mqttMan, bool firstConnection);
  void mqttDisconnectedCallback();
  void mqttCallback(char *topic, uint8_t *payload, unsigned int length);
  void mqttPublishStoveConnected(bool stoveConnected);
  bool mqttPublishData(const String &baseTopic, const String &palaCategory, const JsonDocument &jsonDoc);
  bool mqttPublishHassDiscovery();
  bool mqttPublishUpdate();
  bool executePalaCmd(const String &cmd, String &strJson, bool publish = false);

  void publishTick();
  void udpRequestHandler(WiFiUDP &udpServer);

  void setConfigDefaultValues();
  bool parseConfigJSON(JsonDocument &doc, bool fromWebPage);
  String generateConfigJSON(bool forSaveFile);
  String generateStatusJSON();
  bool appInit(bool reInit);
  const PROGMEM char *getHTMLContent(WebPageForPlaceHolder wp);
  size_t getHTMLContentSize(WebPageForPlaceHolder wp);
  void appInitWebServer(WebServer &server);
  void appRun();

public:
  WPalaControl();
};

#endif

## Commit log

2024-10-25 Update WirelessBase to 2.4.0
2024-11-01 Fix default AP password
    [Main.h]
2024-11-03 Fix new Palazzetti lib usage
    [WPalaControl.cpp]
2024-11-14 Improve Home Assistant tempertaure entities for Hydro stove (#59)
    * Add isFluidType and update home assistant params
    * FLUID can be 0,1 or 2 so not really a boolean
    * Quick fix for min/max until UI research
    * Add UICONFIG and isHydroType
    * Rollback duplication of code
    * Determine the Main temperature sensor
    * Use name for the Main temperature sensor
    * Add additionnal sensors for Hydro
    * Revert to Room instead of Ambient
    * Use Storage Tank wording like docs
    * Comment 2nd and 3rd sensor until clarification
    * Approach based on Android App
    * Better limit condition
    ---------
    [WPalaControl.cpp]
2024-11-16 Add climate (#62)
    * Group FlashString lists
    * More usefull variables grouped
    * Use new tempProbeTopicListArray variable
    * Add Thermostat (climate) entity
    * Add Power command to Thermostat
    * Add temperature command topic
    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
2024-11-16 Fix Fan mode list
    [WPalaControl.cpp]
2024-11-17 Add differential pressure and dp target entities
2024-11-17 Fix missing temperature sensor suffix
    [WPalaControl.cpp]
2024-11-17 Add missing publish for service time
    [WPalaControl.cpp]
2024-11-17 Rounding diffrential pressures
2024-11-17 Remove device_class for service time counter for better display
2024-11-17 Fix service time counter parsing
    [WPalaControl.cpp]
2024-11-17 Fix topic for Room/Return/Tank autodiscover topic
    [WPalaControl.cpp]
2024-11-24 New Hardware Version (V2.0) (#65)
    * Add hw version detection
    * New PCB version
    * Implement Hardware detection
    * Do Not Place J2
    * New box
    * Update box
    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
    [WPalaControl Box.stl, WPalaControl Lid.stl, WPalaControl v17.f3d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]
2024-12-30 Update ArduinoJson Lib to 7.3.0
2025-09-19 Update ArduinoJson Lib to 7.4.2
2025-09-19 Add "Set Time" button to Home Assistant autodiscover
